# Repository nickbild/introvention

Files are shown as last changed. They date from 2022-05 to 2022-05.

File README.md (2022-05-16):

# Introvention

Introvention is a wearable device that seeks to diagnose movement disorders earlier than is presently possible by leveraging machine learning.

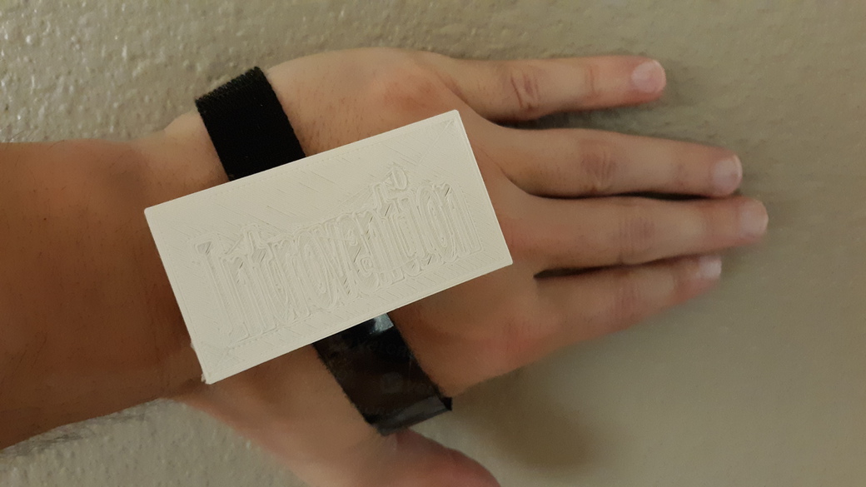
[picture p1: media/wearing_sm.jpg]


## How It Works

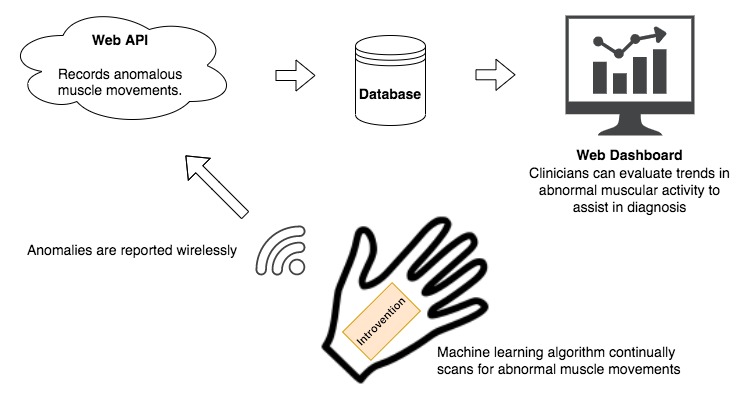
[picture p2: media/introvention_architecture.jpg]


Movement disorders, such as Parkinson’s disease and essential tremor, have presented clinicians with many diagnostic difficulties.  Commonly these types of diseases are not diagnosed until after a patient has started to experience significant symptoms.  It has been recognized in recent years that beginning treatments earlier can lead to better outcomes.  In particular, it has been reported that people with Parkinson’s disease that delay treatment have a worse quality of life than those that are treated early [1].  It makes sense then that we would want to detect such diseases as early as possible, even before symptoms are noticeable, to improve long-term outcomes through intervention.

This is the idea behind Introvention, which is a prototype wearable device that uses a low-power microcontroller and machine learning to detect abnormal muscular movements — tremors, twitches, jerks, etc. — at a subclinical level.  Worn around the clock, Introvention looks for unusual movements and reports them to a clinician to give them additional information that may assist them in making an early diagnosis.

An Arduino Nano 33 IoT microcontroller development board, with an onboard accelerometer is placed in a 3D printed case along with a rechargeable LiPo battery.  The case is worn on the back of the hand.  Introvention continually samples movement data from the accelerometer and feeds it into a K-means clustering algorithm that has been trained to recognize the patterns of normal muscular movements that occur during typical, daily activities.  When anomalous muscular activity is detected, it is transmitted via WiFi to a [web API](https://github.com/nickbild/introvention/blob/main/api.py) that records it in a database.  A [web dashboard](https://github.com/nickbild/introvention/blob/main/dashboard.py) can present this data to a clinician graphically so that they can observe daily trends related to abnormal muscular movements.  The Arduino sketch is [available here](https://github.com/nickbild/introvention/tree/main/introvention_arduino).  The machine learning pipeline can be [viewed here](https://studio.edgeimpulse.com/public/105457/latest).

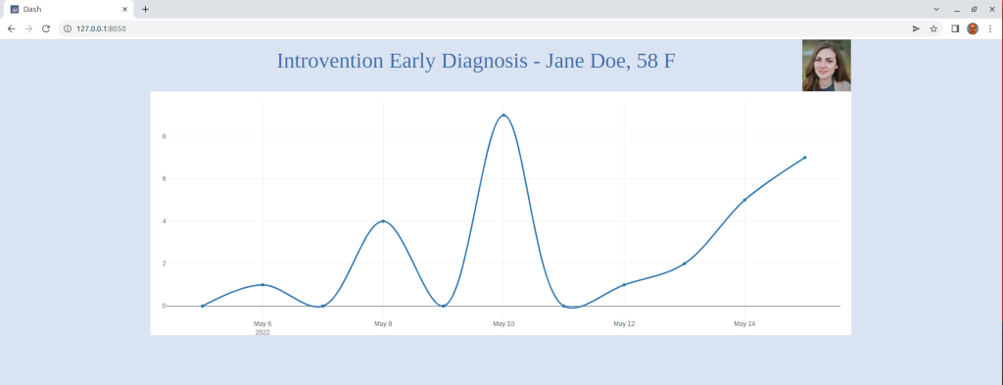
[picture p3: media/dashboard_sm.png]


## Media

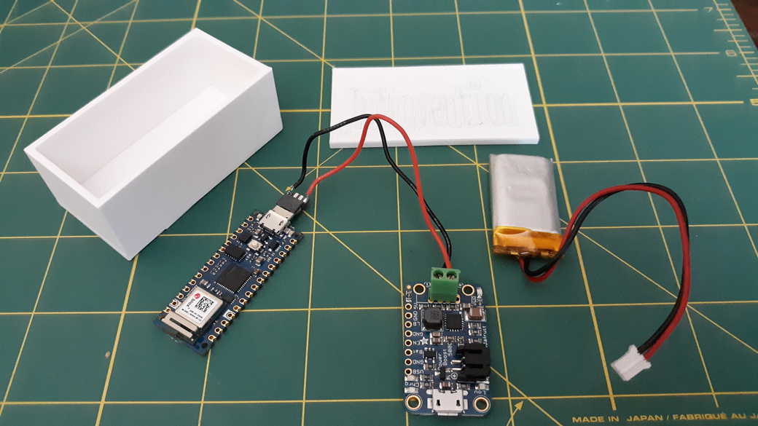
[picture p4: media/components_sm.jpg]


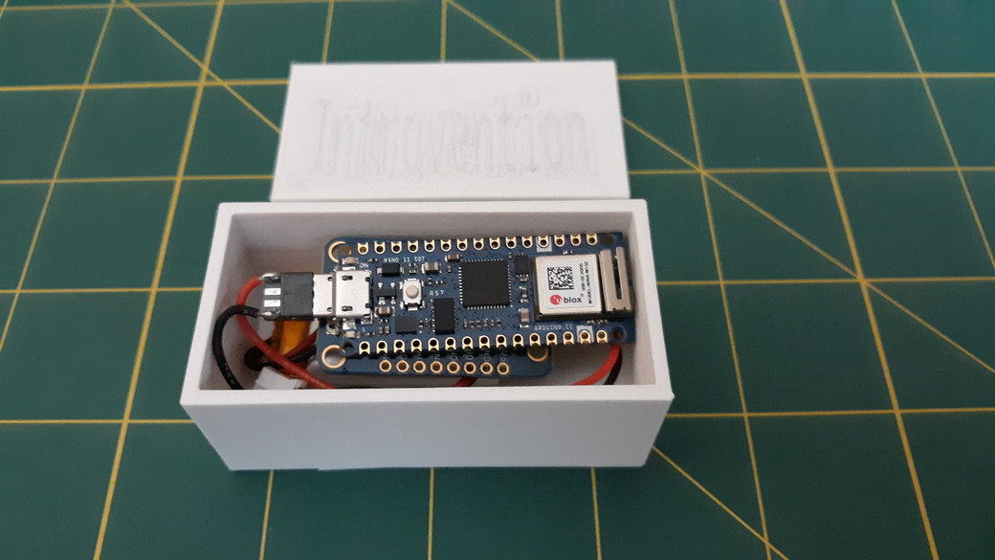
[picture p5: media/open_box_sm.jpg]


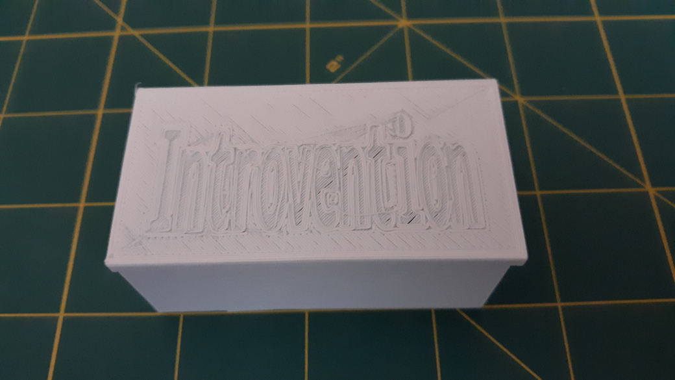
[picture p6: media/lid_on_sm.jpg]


## Bill of Materials

- 1 x Arduino Nano 33 IoT
- 1 x 3.7V to 5.0V power boost converter
- 1 x 350 mAh LiPo battery
- 3D printed case ([case](https://github.com/nickbild/introvention/blob/main/media/introvention_case.stl), [lid](https://github.com/nickbild/introvention/blob/main/media/introvention_lid.stl))
- Velcro straps

## Disclaimer

Introvention is a prototype that has not been approved by the FDA or any other regulatory agency.  It is not suitable for diagnosing any medical condition.

## About the Author

[Nick A. Bild, MS](https://nickbild79.firebaseapp.com/#!/)

## References

[1] Rees RN, Acharya AP, Schrag A, Noyce AJ. An early diagnosis is not the same as a timely diagnosis of Parkinson's disease. F1000Res. 2018;7:F1000 Faculty Rev-1106. Published 2018 Jul 18. doi:10.12688/f1000research.14528.1

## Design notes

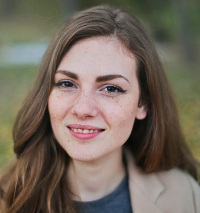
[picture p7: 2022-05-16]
media/pexels-andrea-piacquadio-762020.jpg

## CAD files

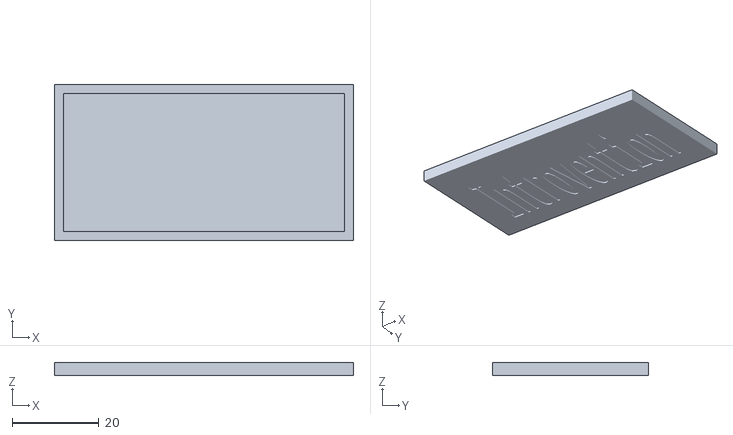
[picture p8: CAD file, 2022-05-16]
media/introvention_lid.stl
69.0 x 36.0 x 3.00

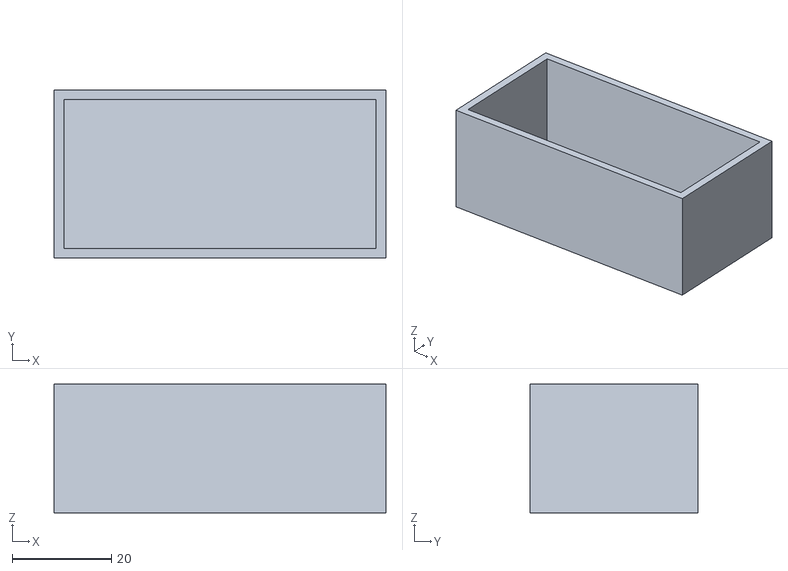
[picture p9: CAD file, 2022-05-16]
media/introvention_case.stl
67.0 x 34.0 x 26.0

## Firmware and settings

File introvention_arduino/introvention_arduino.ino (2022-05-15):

#define __STATIC_FORCEINLINE                   __attribute__((always_inline)) static inline
#define __SSAT(ARG1, ARG2) \
__extension__ \
({                          \
  int32_t __RES, __ARG1 = (ARG1); \
  __ASM volatile ("ssat %0, %1, %2" : "=r" (__RES) :  "I" (ARG2), "r" (__ARG1) : "cc" ); \
  __RES; \
 })
 
#include <stdio.h>
#include <movement_disorder_detection_inferencing.h>
#include "edge-impulse-sdk/classifier/ei_run_classifier.h"
#include "edge-impulse-sdk/porting/ei_classifier_porting.h"
#include "edge-impulse-sdk/dsp/kissfft/kiss_fftr.h"
#include <Arduino_LSM6DS3.h>
#include <WiFiNINA.h>
#include "secrets.h"


// Callback function declaration
static int get_signal_data(size_t offset, size_t length, float *out_ptr);

// Raw features used in inferences.
float features[375] = {};

WiFiClient client;

const char* host = "192.168.1.139";
const char* url = "/anomaly?";

int inference(void) {
    
    signal_t signal;            // Wrapper for raw input buffer
    ei_impulse_result_t result; // Used to store inference output
    EI_IMPULSE_ERROR res;       // Return code from inference

    // Calculate the length of the buffer
    size_t buf_len = sizeof(features) / sizeof(features[0]);

    // Make sure that the length of the buffer matches expected input length
    if (buf_len != EI_CLASSIFIER_DSP_INPUT_FRAME_SIZE) {
        printf("ERROR: The size of the input buffer is not correct.\r\n");
        printf("Expected %d items, but got %d\r\n", 
                EI_CLASSIFIER_DSP_INPUT_FRAME_SIZE, 
                (int)buf_len);
        return 1;
    }

    // Assign callback function to fill buffer used for preprocessing/inference
    signal.total_length = EI_CLASSIFIER_DSP_INPUT_FRAME_SIZE;
    signal.get_data = &get_signal_data;

    // Perform DSP pre-processing and inference
    res = run_classifier(&signal, &result, false);

    // Print return code and how long it took to perform inference
    printf("run_classifier returned: %d\r\n", res);
    printf("Timing: DSP %d ms, inference %d ms, anomaly %d ms\r\n", 
            result.timing.dsp, 
            result.timing.classification, 
            result.timing.anomaly);

    Serial.println(result.anomaly);

    // Report anomalies to web API.
    if (result.anomaly > 1) {
      if (!client.connect(host, 5000)) {
        Serial.println("Connection failed.");
      }
      
      client.print(String("GET ") + url + "count=1 HTTP/1.1\r\n" +
      "Host: " + host + "\r\n" +
      "Connection: close\r\n\r\n");

       while(client.available()) {}
  
       client.stop();
    }

    return 0;
}

// Callback: fill a section of the out_ptr buffer when requested
static int get_signal_data(size_t offset, size_t length, float *out_ptr) {
    for (size_t i = 0; i < length; i++) {
        out_ptr[i] = (features + offset)[i];
    }

    return EIDSP_OK;
}

void setup() {
  Serial.begin(115200);

  if (!IMU.begin()) {
    Serial.println("Failed to initialize IMU!");
    while (1);
  }

   WiFi.begin(SSID, PASSWORD);
  
  while (WiFi.status() != WL_CONNECTED) {
    delay(500);
    Serial.print(".");
  }

}

void loop() {
  // Collect 2 seconds of accelerometer data.
  getAccelData();
  // Run anomaly detection.
  inference();
}

void getAccelData() {
  float x, y, z;
  int cnt = 0;
  int idx = 0;

  // Get 125 samples (~2 seconds).
  while (true) {
    if (IMU.accelerationAvailable()) {
      IMU.readAcceleration(x, y, z);

      // Store in global array used by inference engine.
      features[idx] = x;
      idx++;
      features[idx] = y;
      idx++;
      features[idx] = z;
      idx++;

      cnt += 1;
      if (cnt >=125) {
        break;  
      }
    }
  }
}

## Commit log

2022-05-15 Initial commit.
    [abnormal_0.csv, abnormal_1.csv, abnormal_10.csv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]
2022-05-16 Update documentation.
    [introvention_case.stl]
